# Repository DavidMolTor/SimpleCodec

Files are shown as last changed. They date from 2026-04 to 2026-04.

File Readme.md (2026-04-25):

# PICO FX

A simple stereo guitar effects platform using an RP Pico 2 development board.

## Introduction

This module is designed to be used as a development platform for guitar effects running on the RP2350 architecture.

The module contains a CS4272 codec with stereo inputs and outputs. It also includes a set of clean buffers to match the guitar and other effects in the chain.

All the power regulation is done through LDO regulators that prioritize low ripple in exchange for worse efficiency.

It is designed to work with 9V intput voltage. It also has a set of headers for it to be able to interface with a control board in the future.

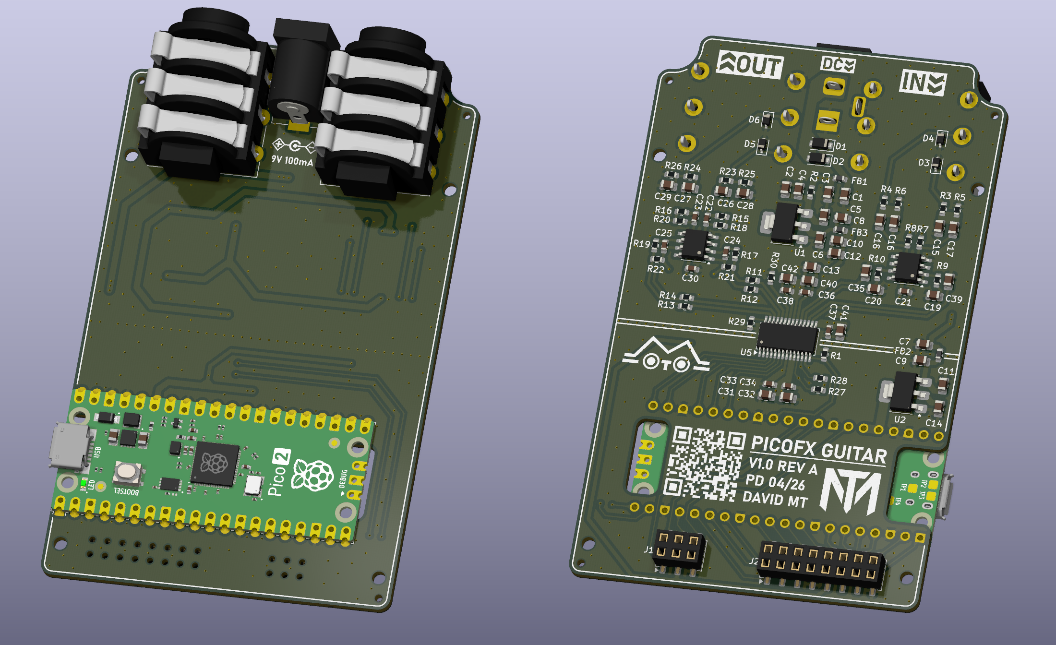
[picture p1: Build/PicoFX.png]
PICO FX


## Features

 - Clear separation between digital and analog sections.

 - Stereo input and output.

 - Clean voltage delivery.

 - Flexible interface for controls.

 - Easy future development.

 - Afforable BOM.

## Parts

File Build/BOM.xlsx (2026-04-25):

Designator | Qty | Value | Footprint | JLCPCB Part | Manufacturer Part
A1 | 1 | RP_PICO_2 | RP_PICO_2_SMD | C41407547 | Pico 2
C1,C2,C3,C4,C5,C6,C7,C8,C9,C10,C11,C12,C13,C14,C17,C18,C26,C27,C42 | 19 | 10u | 0805_2012Metric | C15850 | CL21A106KAYNNNE
C15,C16,C19,C20,C28,C29,C35,C39 | 8 | 2.2n | 0805_2012Metric | C28260 | CL21C222JBFNNNE
C21,C30,C33,C34,C36,C37,C38 | 7 | 100n | 0603_1608Metric | C14663 | CC0603KRX7R9BB104
C22,C23,C24,C25 | 4 | 330p | 0603_1608Metric | C1664 | CL10C331JB8NNNC
C31,C32,C40,C41 | 4 | 1u | 0805_2012Metric | C28323 | CL21B105KBFNNNE
D1 | 1 | SMF10CA | SOD-123F | C19077505 | SMF10CA
D2 | 1 | DSK24 | SOD-123F | C22466352 | DSK24
D3,D4,D5,D6 | 4 | H15VSD3B | SOD-323 | C20615814 | H15VSD3B
FB1,FB2,FB3 | 3 | 850 | 0603_1608Metric | C13415 | SDCL1608C68NJTDF
J1 | 1 | RPI_ADC | HEADER_THROUGH_2x03_P2.54mm | C42163131 | HC-PM254-5.0H-2x3PS-02A
J2 | 1 | RP_GPIO | HEADER_THROUGH_2x08_P2.54mm | C42163136 | HC-PM254-5.0H-2x8PS
R1,R25,R26,R27,R28,R29,R30 | 7 | 47K | 0603_1608Metric | C25819 | 0603WAF4702T5E
R2,R3,R4,R23,R24 | 5 | 100 | 0603_1608Metric | C22775 | 0603WAF1000T5E
R5,R6,R7,R8 | 4 | 1M | 0603_1608Metric | C22935 | 0603WAF1004T5E
R9,R10 | 2 | 1K | 0603_1608Metric | C21190 | 0603WAF1001T5E
R11,R12,R13,R14 | 4 | 15K | 0603_1608Metric | C22809 | 0603WAF1502T5E
R15,R16,R21,R22 | 4 | 11K | 0603_1608Metric | C25950 | 0603WAF1102T5E
R17,R18,R19,R20 | 4 | 820 | 0603_1608Metric | C23253 | 0603WAF8200T5E
U1 | 1 | AMS1117-5.0 | SOT-223-3_TabPin2 | C6187 | AMS1117-5.0
U2 | 1 | AMS1117-3.3 | SOT-223-3_TabPin2 | C6186 | AMS1117-3.3
U3,U4 | 2 | MCP6002-xSN | SOIC-8_3.9x4.9mm_P1.27mm | C7377 | MCP6002T-I/SN
U5 | 1 | CS4272 | TSSOP-28_4.4x9.7mm_P0.65mm | C2151111 | CS4272-CZZR
X1-GUITAR | 2 | JACK_GUITAR | NMJ6HCD2 | C368502 | NMJ6HCD2
X1-DC | 1 | JACK_DC | BarrelJack_Horizontal | C319099 | DC-005-2.5A-2.0

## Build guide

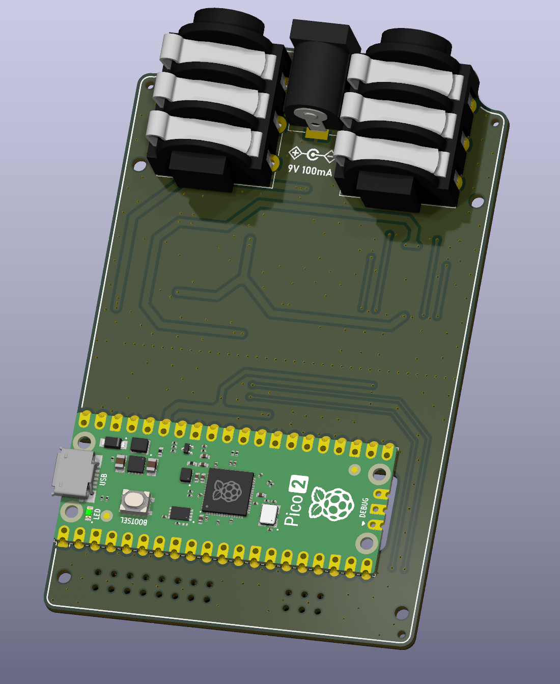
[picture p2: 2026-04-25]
Build/Front.png

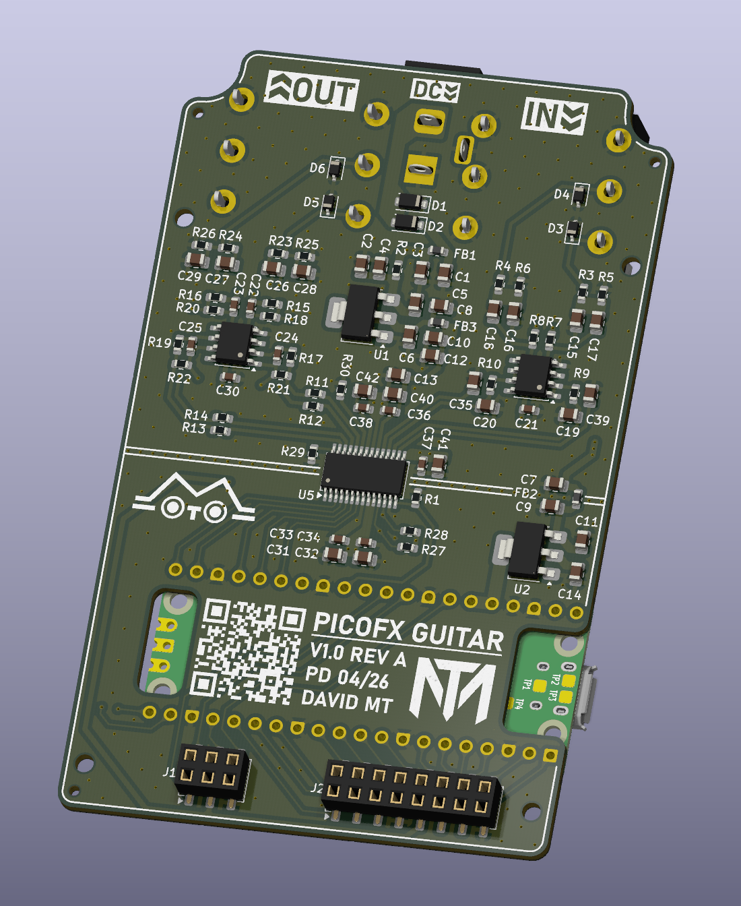
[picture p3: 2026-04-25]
Build/Back.png

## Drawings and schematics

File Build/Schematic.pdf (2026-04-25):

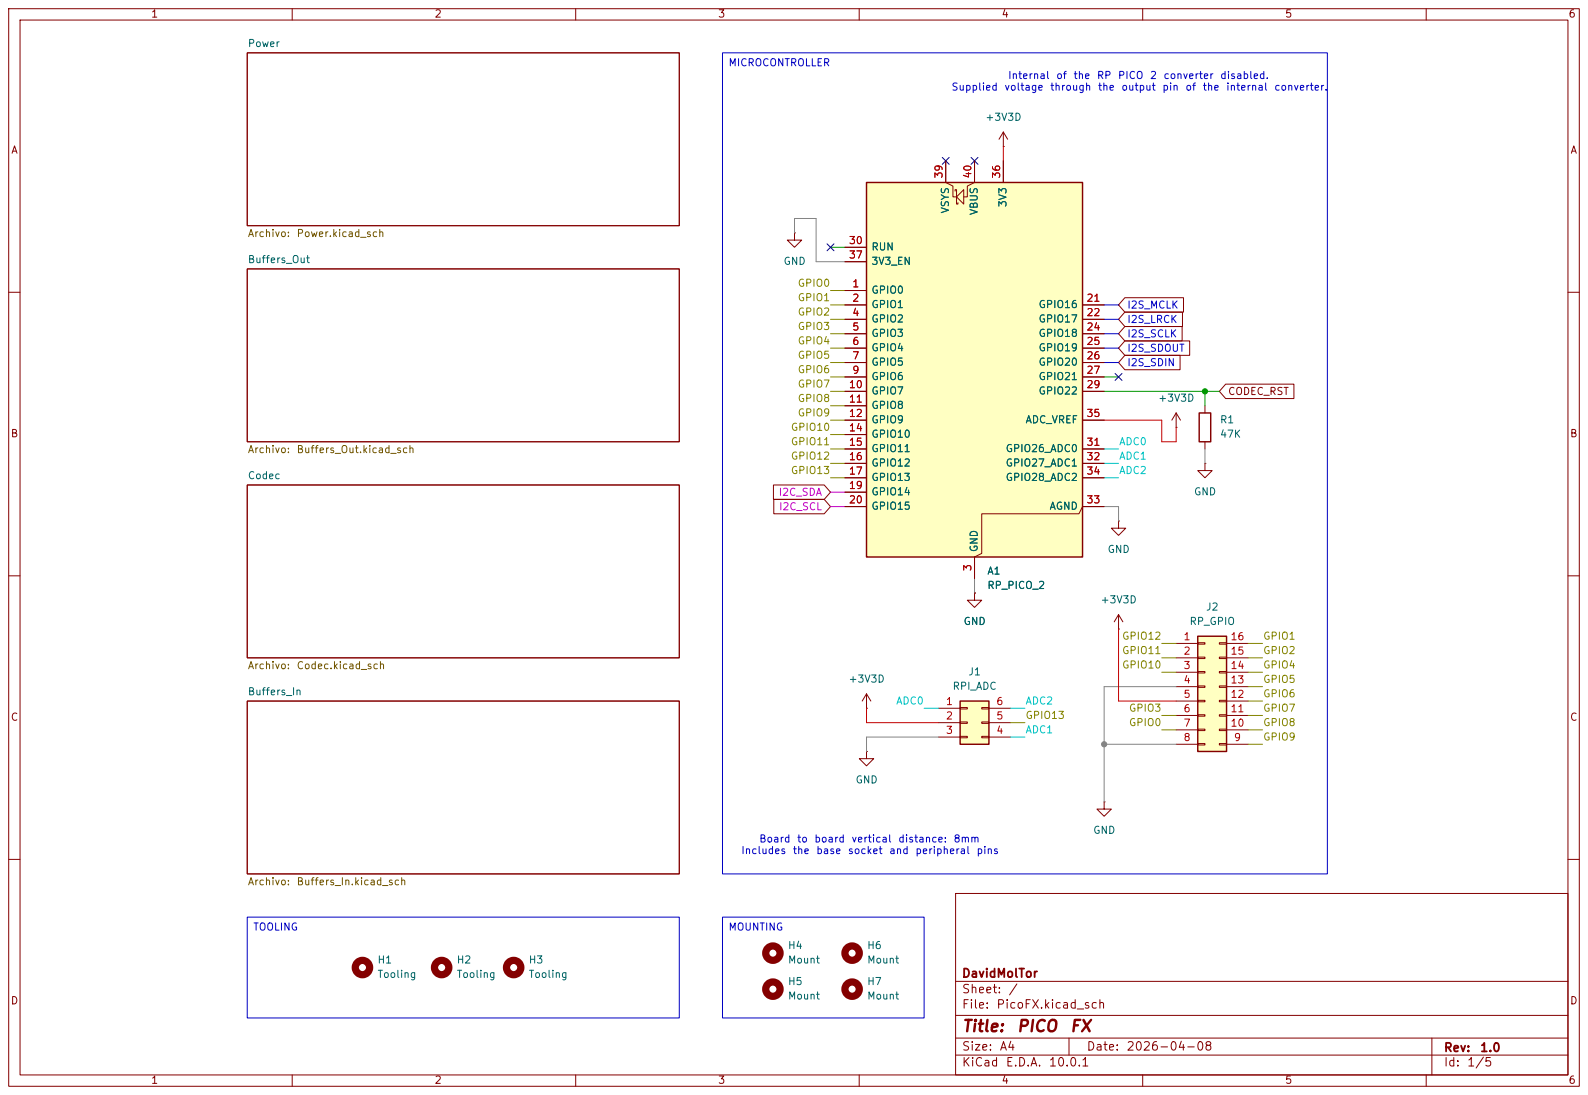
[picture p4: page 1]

Internal of the RP PICO 2 converter disabled. Supplied voltage through the output pin of the internal converter.

Includes the base socket and peripheral pins GND

Board to board vertical distance: 8mm

Size: A4 | Rev: 1.0
KiCad E.D.A. 10.0.1 | Id: 1/5

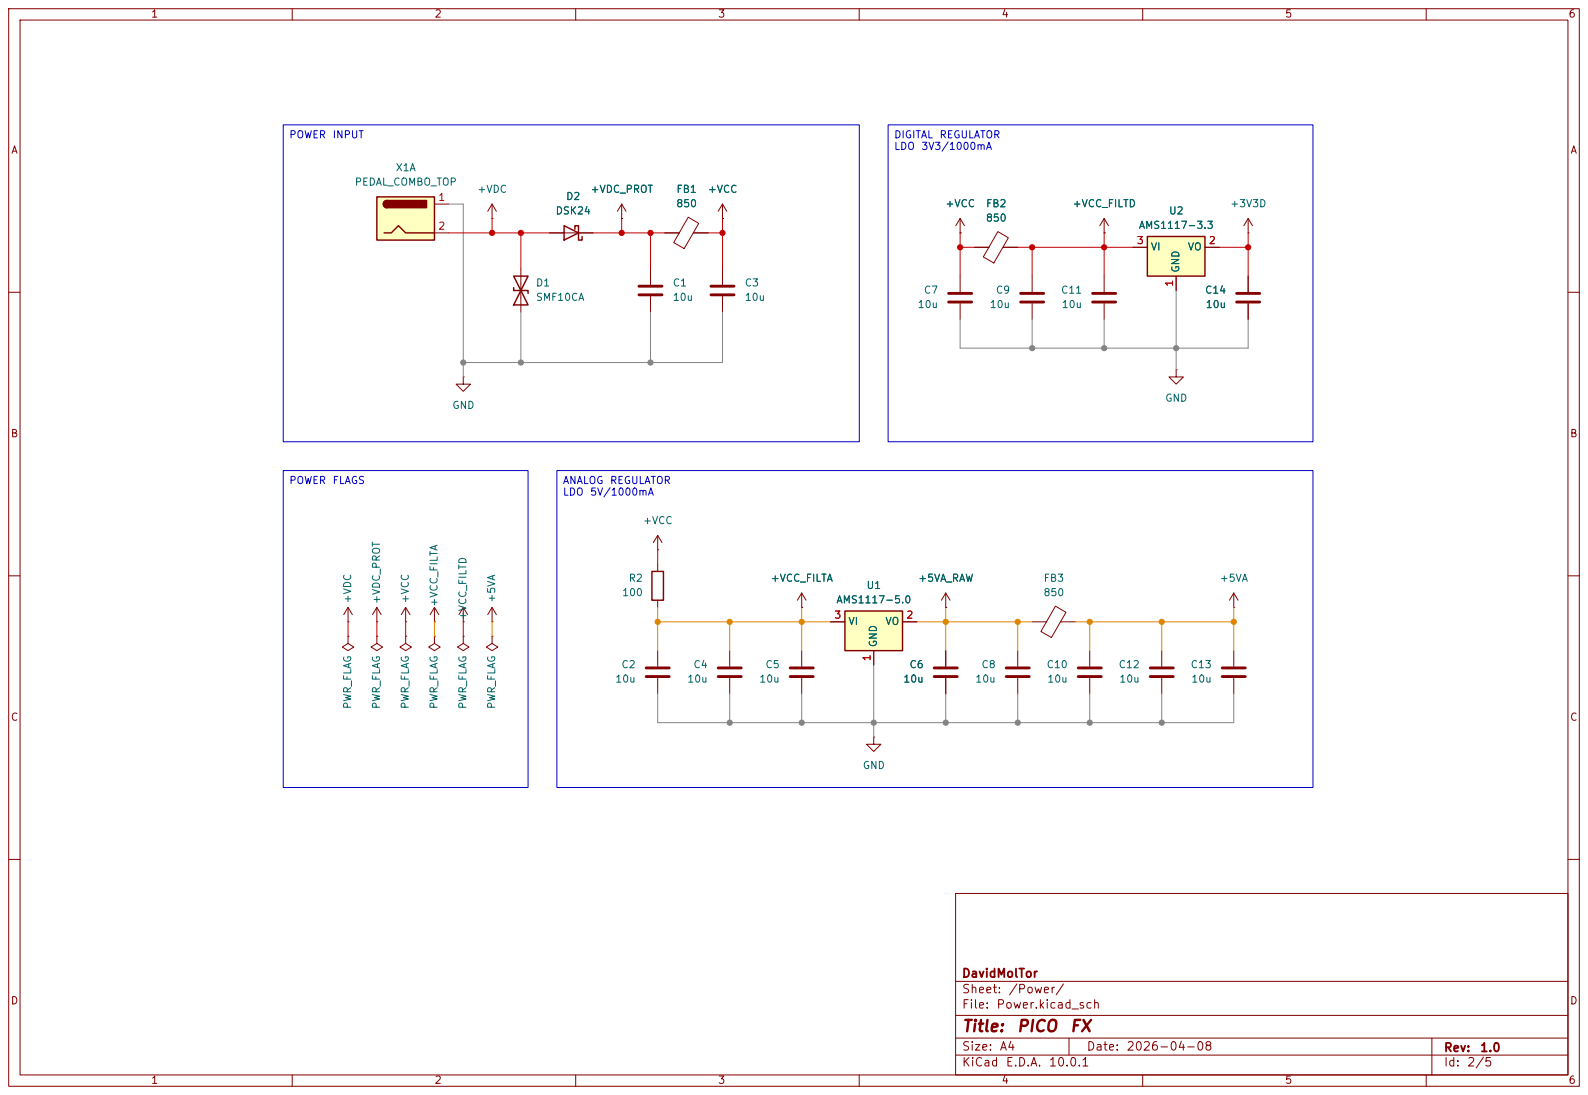
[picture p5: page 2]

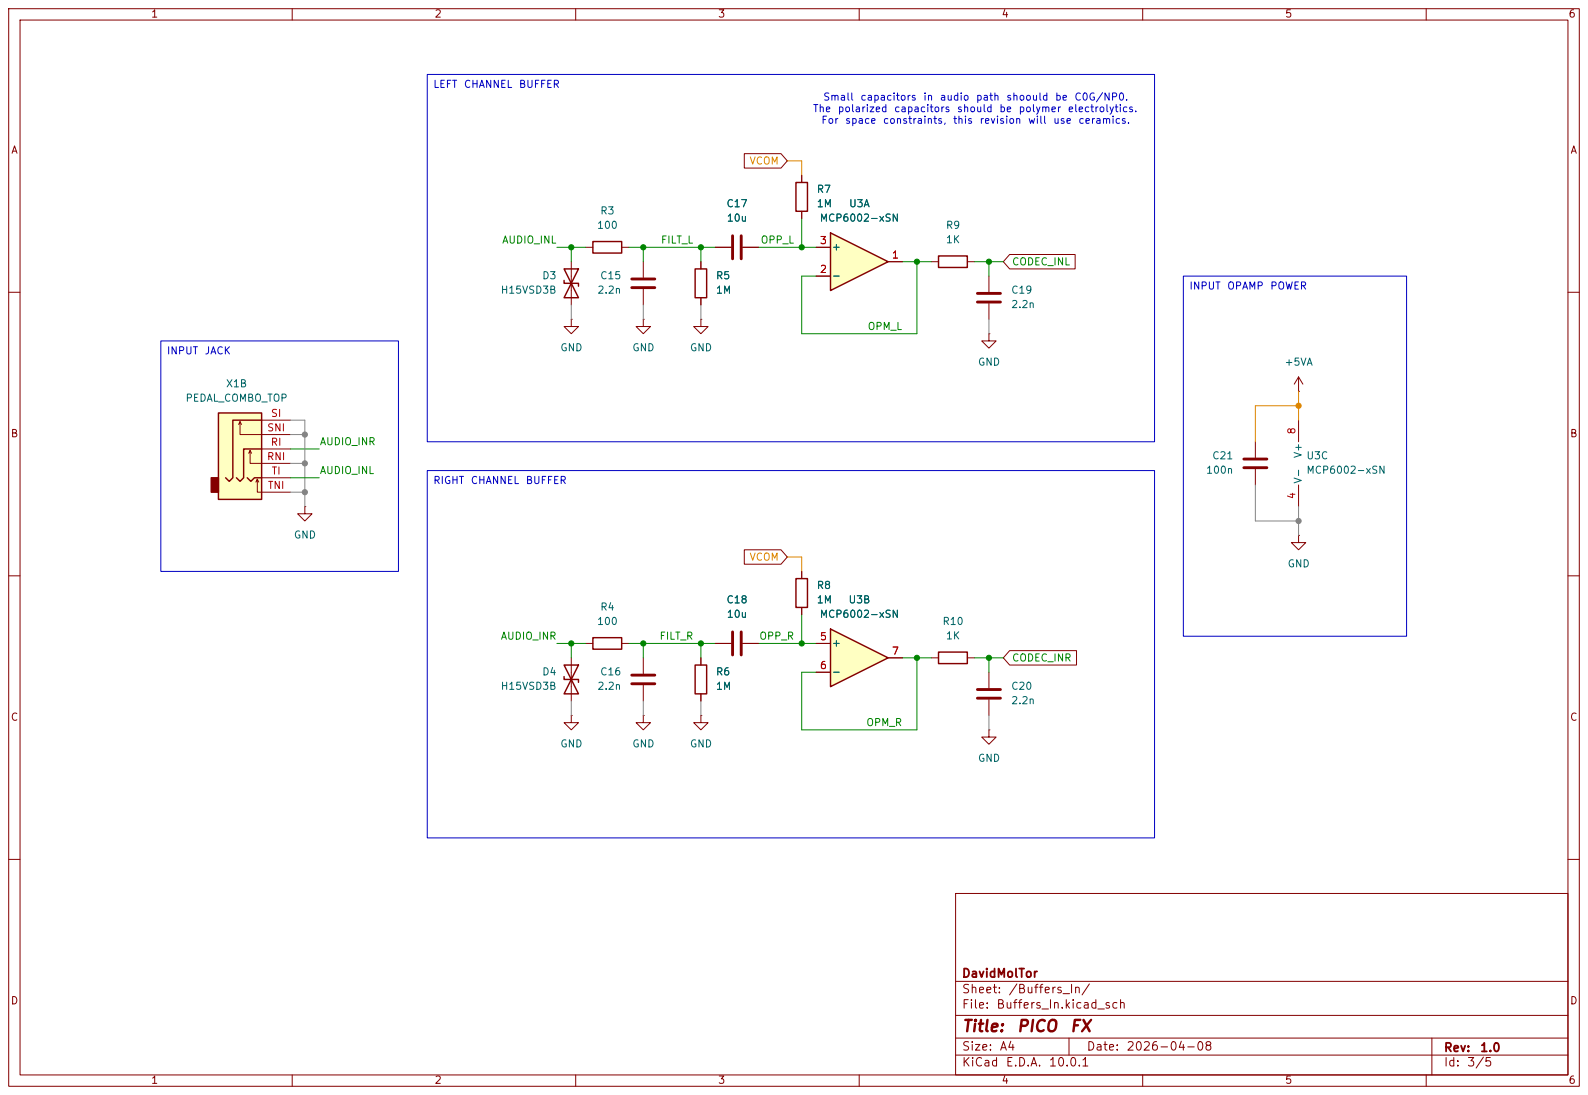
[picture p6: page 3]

Small capacitors in audio path shoould be C0G/NP0. The polarized capacitors should be polymer electrolytics. For space constraints, this revision will use ceramics. U3A MCP6002-xSN

RI RNI SI SNI TI TNI X1B

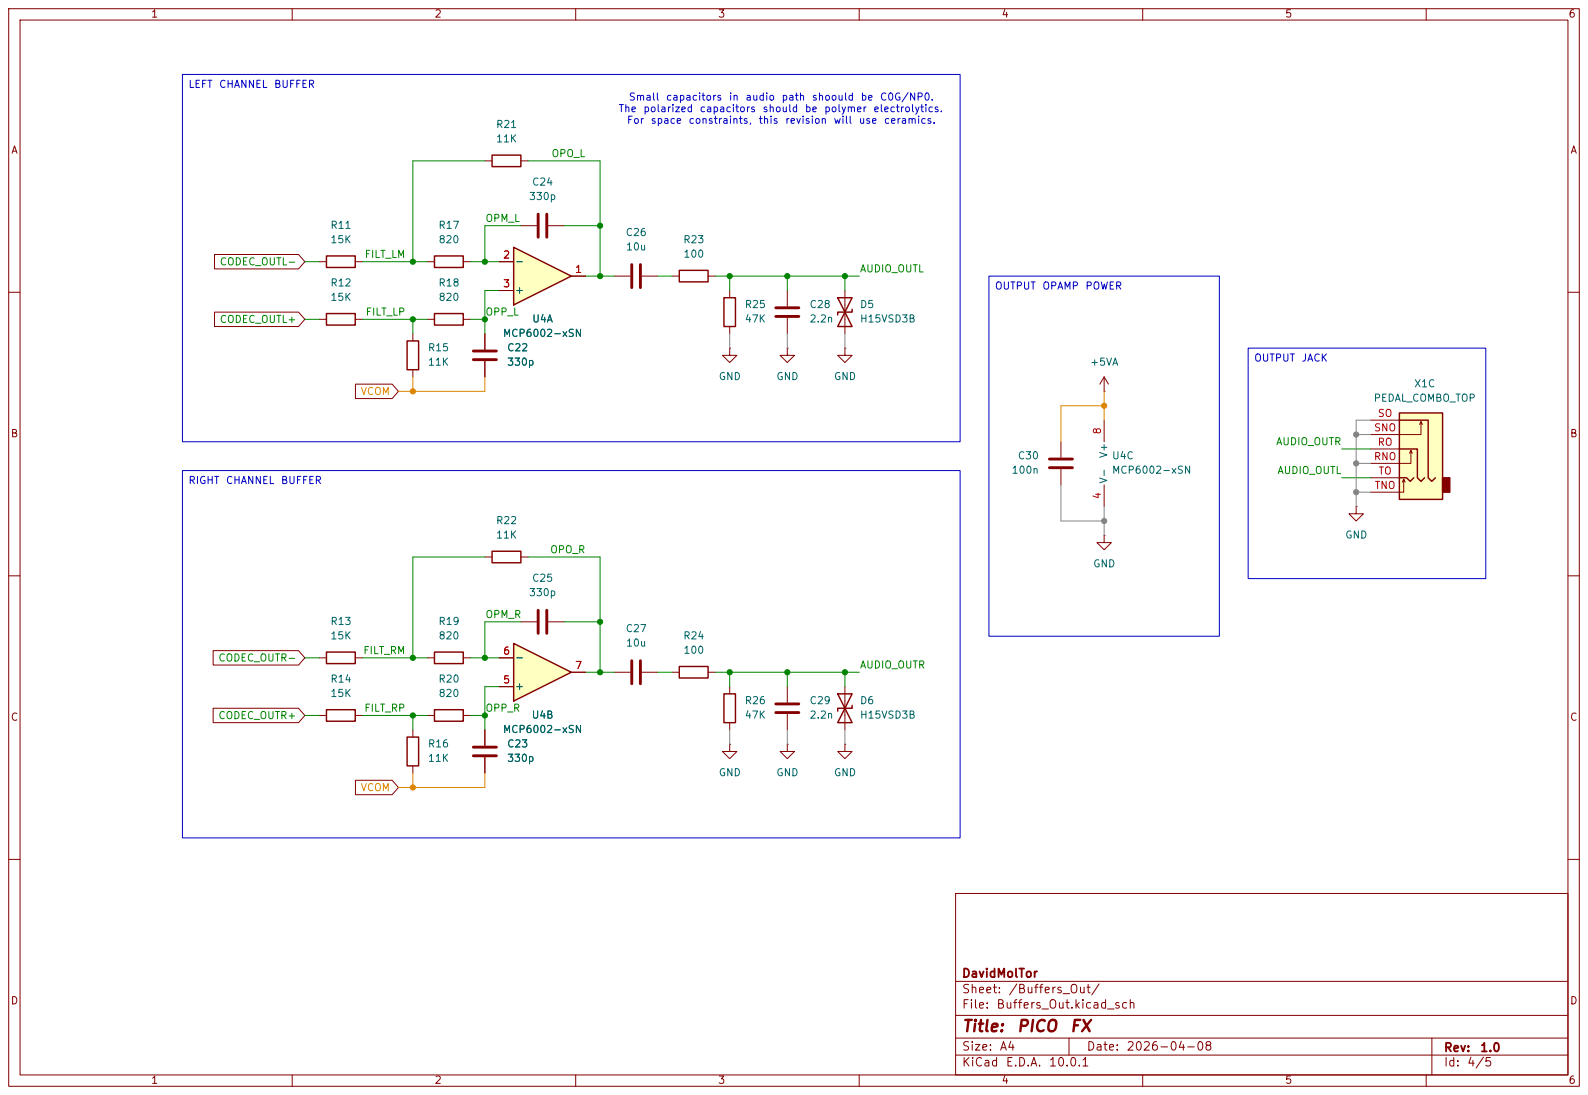
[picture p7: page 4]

Small capacitors in audio path shoould be C0G/NP0. The polarized capacitors should be polymer electrolytics. For space constraints, this revision will use ceramics. U4A MCP6002-xSN

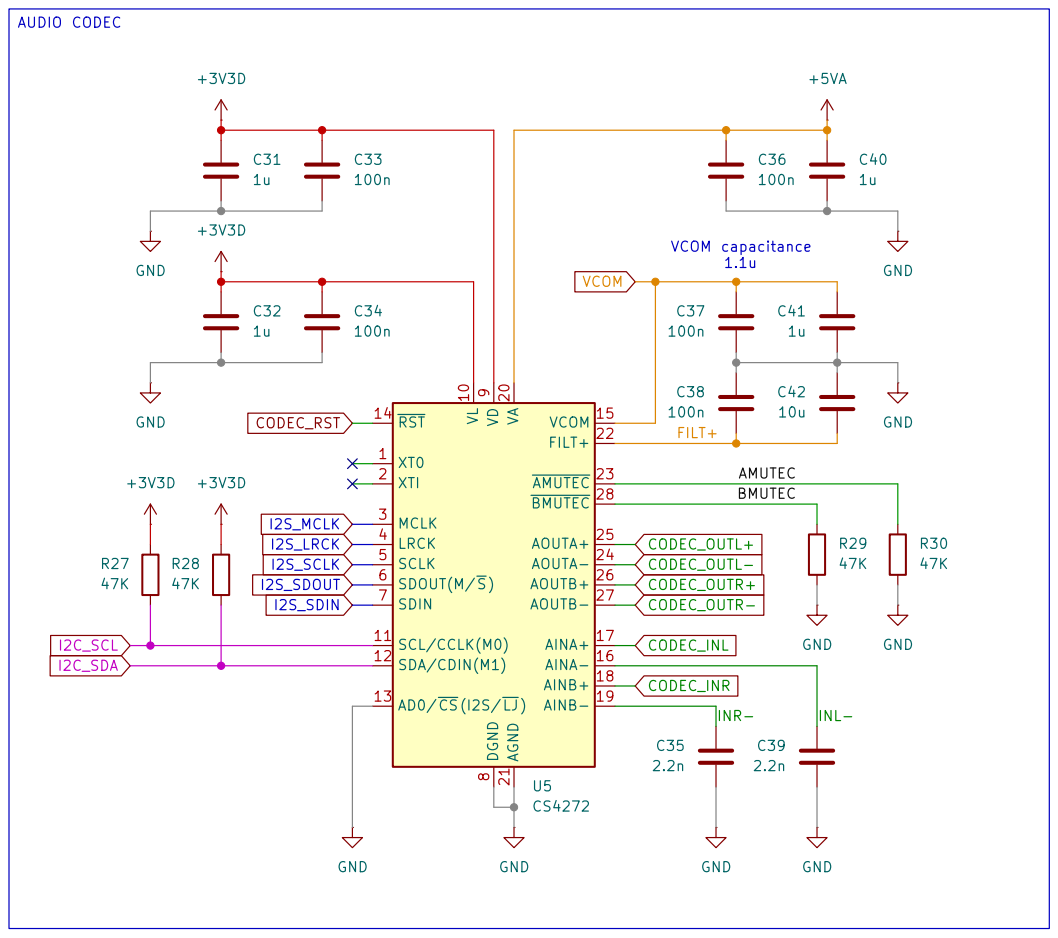
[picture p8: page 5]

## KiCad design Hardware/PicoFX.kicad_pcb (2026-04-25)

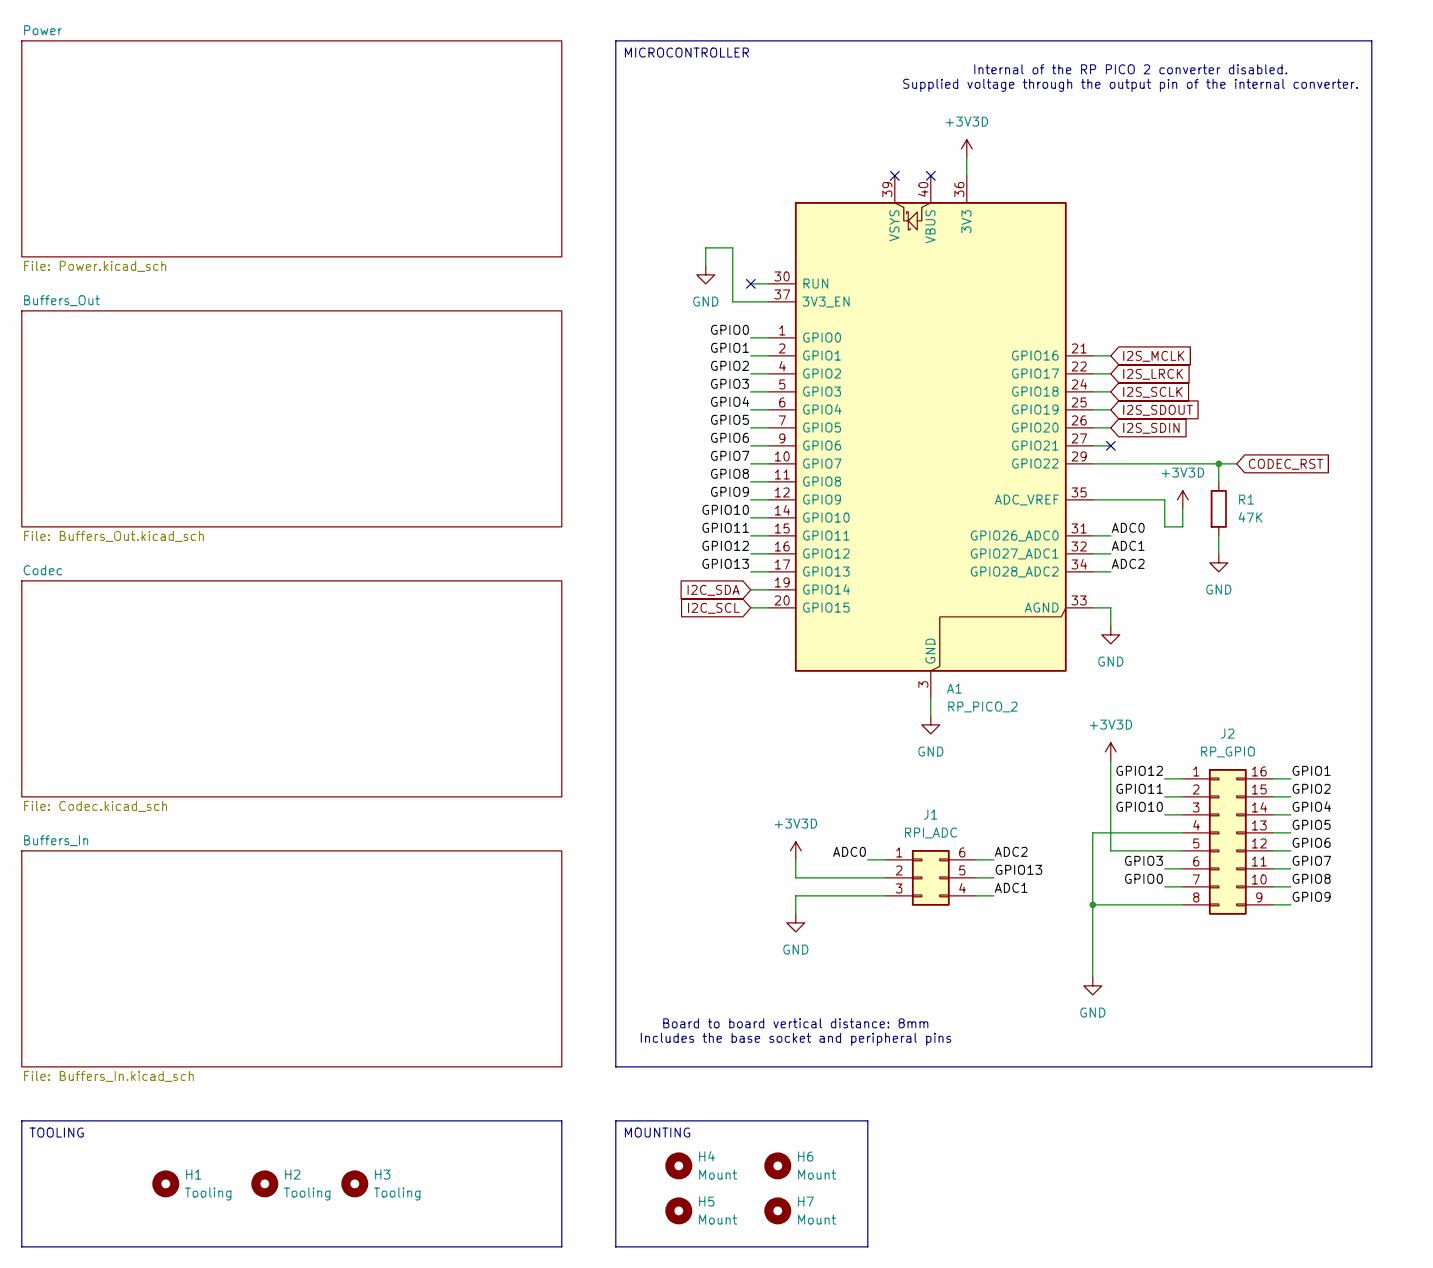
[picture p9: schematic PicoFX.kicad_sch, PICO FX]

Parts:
A1: RP_PICO_2; RP_PICO_2_SMD
H1, H2, H3: Tooling; ToolingHole_1.152mm
H4, H5, H6, H7: Mount; MountingHole_2.2mm_M2
J1: RPI_ADC; HEADER_THROUGH_2x03_P2.54mm
J2: RP_GPIO; HEADER_THROUGH_2x08_P2.54mm
R1: 47K; R_0603_1608Metric

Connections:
+3V3D: A1.35 (ADC_VREF), A1.36 (3V3), J1.2, J2.5; also elsewhere on the board
/ADC0: A1.31 (GPIO26_ADC0), J1.1
/ADC1: A1.32 (GPIO27_ADC1), J1.4
/ADC2: A1.34 (GPIO28_ADC2), J1.6
/GPIO0: A1.1 (GPIO0), J2.7
/GPIO1: A1.2 (GPIO1), J2.16
/GPIO2: A1.4 (GPIO2), J2.15
/GPIO3: A1.5 (GPIO3), J2.6
/GPIO4: A1.6 (GPIO4), J2.14
/GPIO5: A1.7 (GPIO5), J2.13
/GPIO6: A1.9 (GPIO6), J2.12
/GPIO7: A1.10 (GPIO7), J2.11
/GPIO8: A1.11 (GPIO8), J2.10
/GPIO9: A1.12 (GPIO9), J2.9
/GPIO10: A1.14 (GPIO10), J2.3
/GPIO11: A1.15 (GPIO11), J2.2
/GPIO12: A1.16 (GPIO12), J2.1
/GPIO13: A1.17 (GPIO13), J1.5
CODEC_RST: A1.29 (GPIO22), R1.1; also elsewhere on the board
GND: A1.3 (GND), A1.8 (GND), A1.13 (GND), A1.18 (GND), A1.23 (GND), A1.28 (GND), A1.33 (AGND), A1.37 (3V3_EN), A1.38 (GND), J1.3, J2.4, J2.8, R1.2; also elsewhere on the board
I2C_SCL: A1.20 (GPIO15); also elsewhere on the board
I2C_SDA: A1.19 (GPIO14); also elsewhere on the board
I2S_LRCK: A1.22 (GPIO17); also elsewhere on the board
I2S_MCLK: A1.21 (GPIO16); also elsewhere on the board
I2S_SCLK: A1.24 (GPIO18); also elsewhere on the board
I2S_SDIN: A1.26 (GPIO20); also elsewhere on the board
I2S_SDOUT: A1.25 (GPIO19); also elsewhere on the board

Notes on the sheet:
Board to board vertical distance: 8mm Includes the base socket and peripheral pins
Internal of the RP PICO 2 converter disabled. Supplied voltage through the output pin of the internal converter.
MICROCONTROLLER
TOOLING
MOUNTING

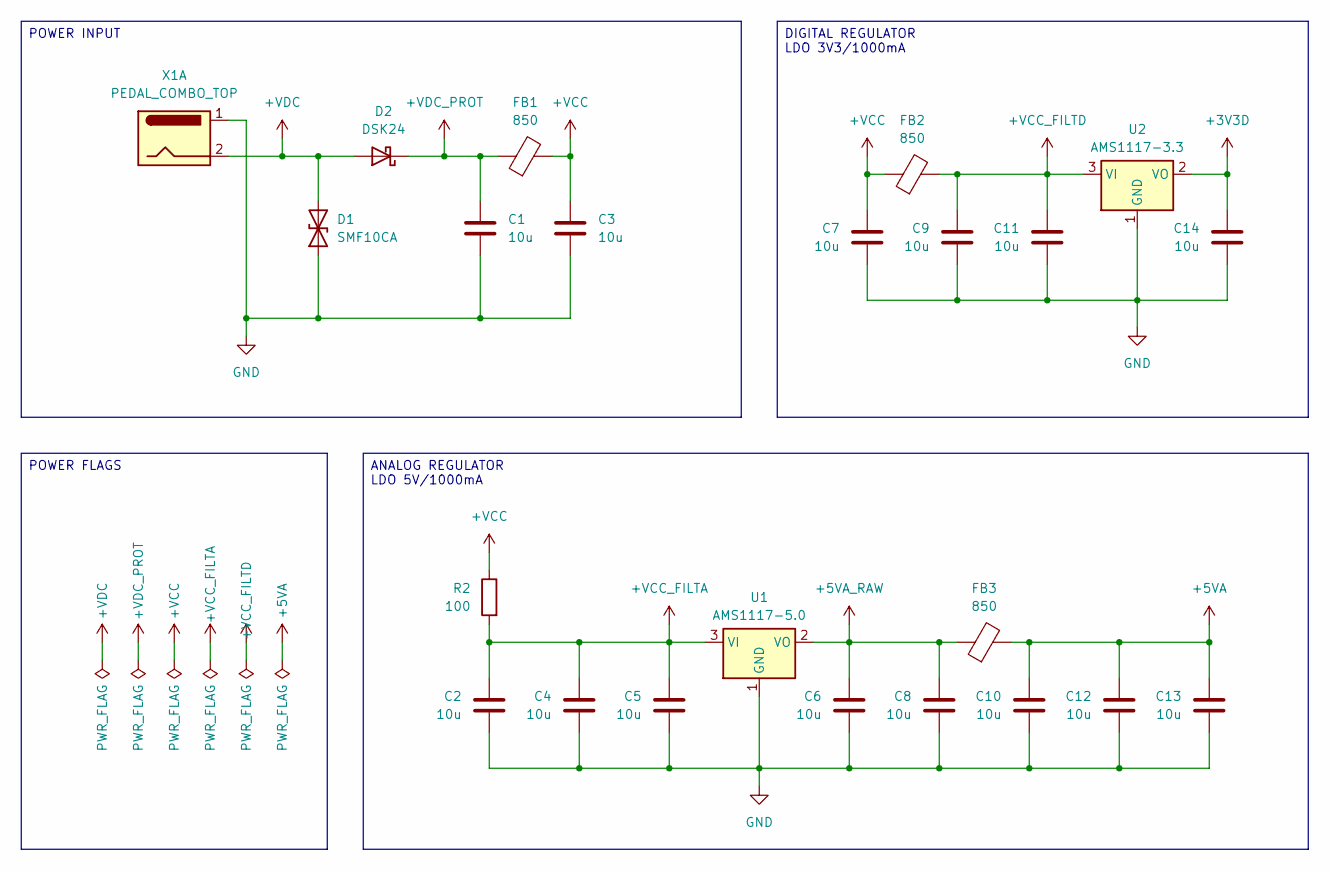
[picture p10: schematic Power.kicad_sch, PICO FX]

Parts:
C1, C2, C3, C4, C5, C6, C7, C8, C9, C10, C11, C12, C13, C14: 10u; C_0805_2012Metric
D1: SMF10CA; D_SOD-123F
D2: DSK24; D_SOD-123F
FB1, FB2, FB3: 850; L_0603_1608Metric
R2: 100; R_0603_1608Metric
U1: AMS1117-5.0; SOT-223-3_TabPin2
U2: AMS1117-3.3; SOT-223-3_TabPin2
X1: PEDAL_COMBO_TOP

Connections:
+3V3D: C14.1, U2.2 (VO); also elsewhere on the board
+5VA: C10.1, C12.1, C13.1, FB3.2; also elsewhere on the board
+5VA_RAW: C6.1, C8.1, FB3.1, U1.2 (VO)
+VCC: C3.1, C7.1, FB1.2, FB2.1, R2.1
+VCC_FILTA: C2.1, C4.1, C5.1, R2.2, U1.3 (VI)
+VCC_FILTD: C9.1, C11.1, FB2.2, U2.3 (VI)
+VDC: D1.2 (A2), D2.2 (A), X1.2
+VDC_PROT: C1.1, D2.1 (K), FB1.1
GND: C1.2, C2.2, C3.2, C4.2, C5.2, C6.2, C7.2, C8.2, C9.2, C10.2, C11.2, C12.2, C13.2, C14.2, D1.1 (A1), U1.1 (GND), U2.1 (GND), X1.1; also elsewhere on the board

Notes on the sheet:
DIGITAL REGULATOR LDO 3V3/1000mA
POWER INPUT
ANALOG REGULATOR LDO 5V/1000mA
POWER FLAGS

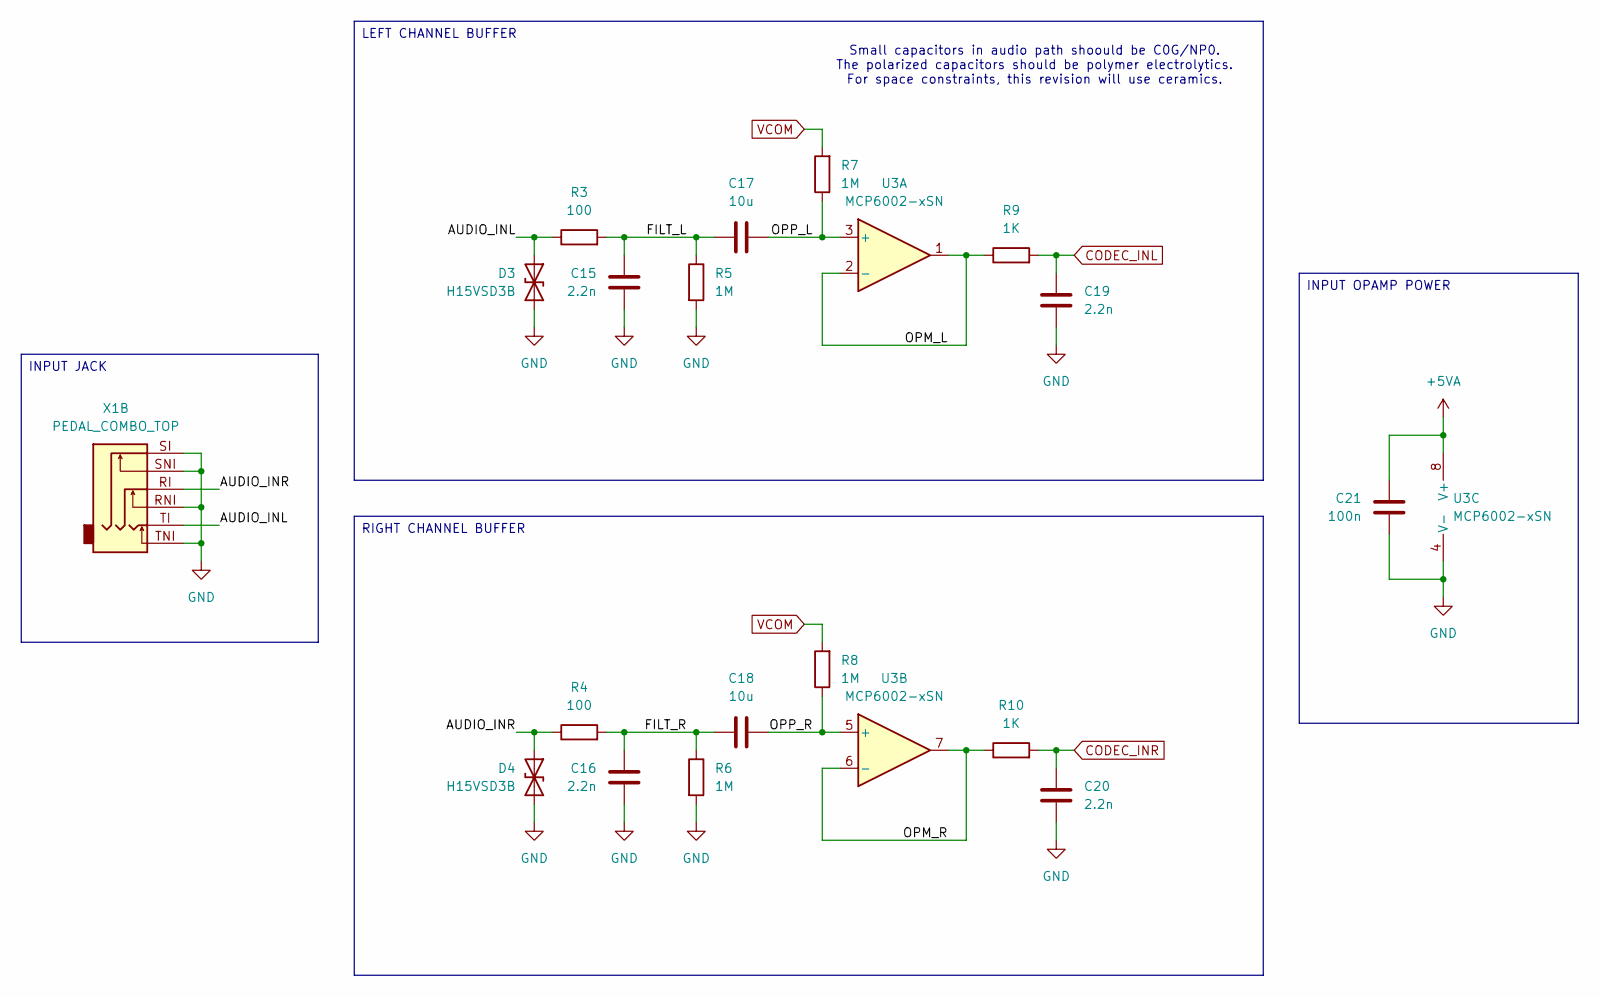
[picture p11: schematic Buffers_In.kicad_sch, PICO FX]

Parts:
C15, C16, C19, C20: 2.2n; C_0805_2012Metric
C17, C18: 10u; C_0805_2012Metric
C21: 100n; C_0603_1608Metric
D3, D4: H15VSD3B; D_SOD-323
R3, R4: 100; R_0603_1608Metric
R5, R6, R7, R8: 1M; R_0603_1608Metric
R9, R10: 1K; R_0603_1608Metric
U3: MCP6002-xSN; SOIC-8_3.9x4.9mm_P1.27mm
X1: PEDAL_COMBO_TOP

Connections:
+5VA: C21.1, U3.8 (V+); also elsewhere on the board
/Buffers_In/AUDIO_INL: D3.1 (A1), R3.1, X1.TI
/Buffers_In/AUDIO_INR: D4.1 (A1), R4.1, X1.RI
/Buffers_In/FILT_L: C15.2, C17.1, R3.2, R5.1
/Buffers_In/FILT_R: C16.2, C18.1, R4.2, R6.1
/Buffers_In/OPM_L: R9.1, U3.1, U3.2 (-)
/Buffers_In/OPM_R: R10.1, U3.6 (-), U3.7
/Buffers_In/OPP_L: C17.2, R7.1, U3.3 (+)
/Buffers_In/OPP_R: C18.2, R8.1, U3.5 (+)
CODEC_INL: C19.1, R9.2; also elsewhere on the board
CODEC_INR: C20.1, R10.2; also elsewhere on the board
GND: C15.1, C16.1, C19.2, C20.2, C21.2, D3.2 (A2), D4.2 (A2), R5.2, R6.2, U3.4 (V-), X1.RNI, X1.SI, X1.SNI, X1.TNI; also elsewhere on the board
VCOM: R7.2, R8.2; also elsewhere on the board

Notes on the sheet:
Small capacitors in audio path shoould be C0G/NP0. The polarized capacitors should be polymer electrolytics. For space constraints, this revision will use ceramics.
LEFT CHANNEL BUFFER
INPUT OPAMP POWER
INPUT JACK
RIGHT CHANNEL BUFFER

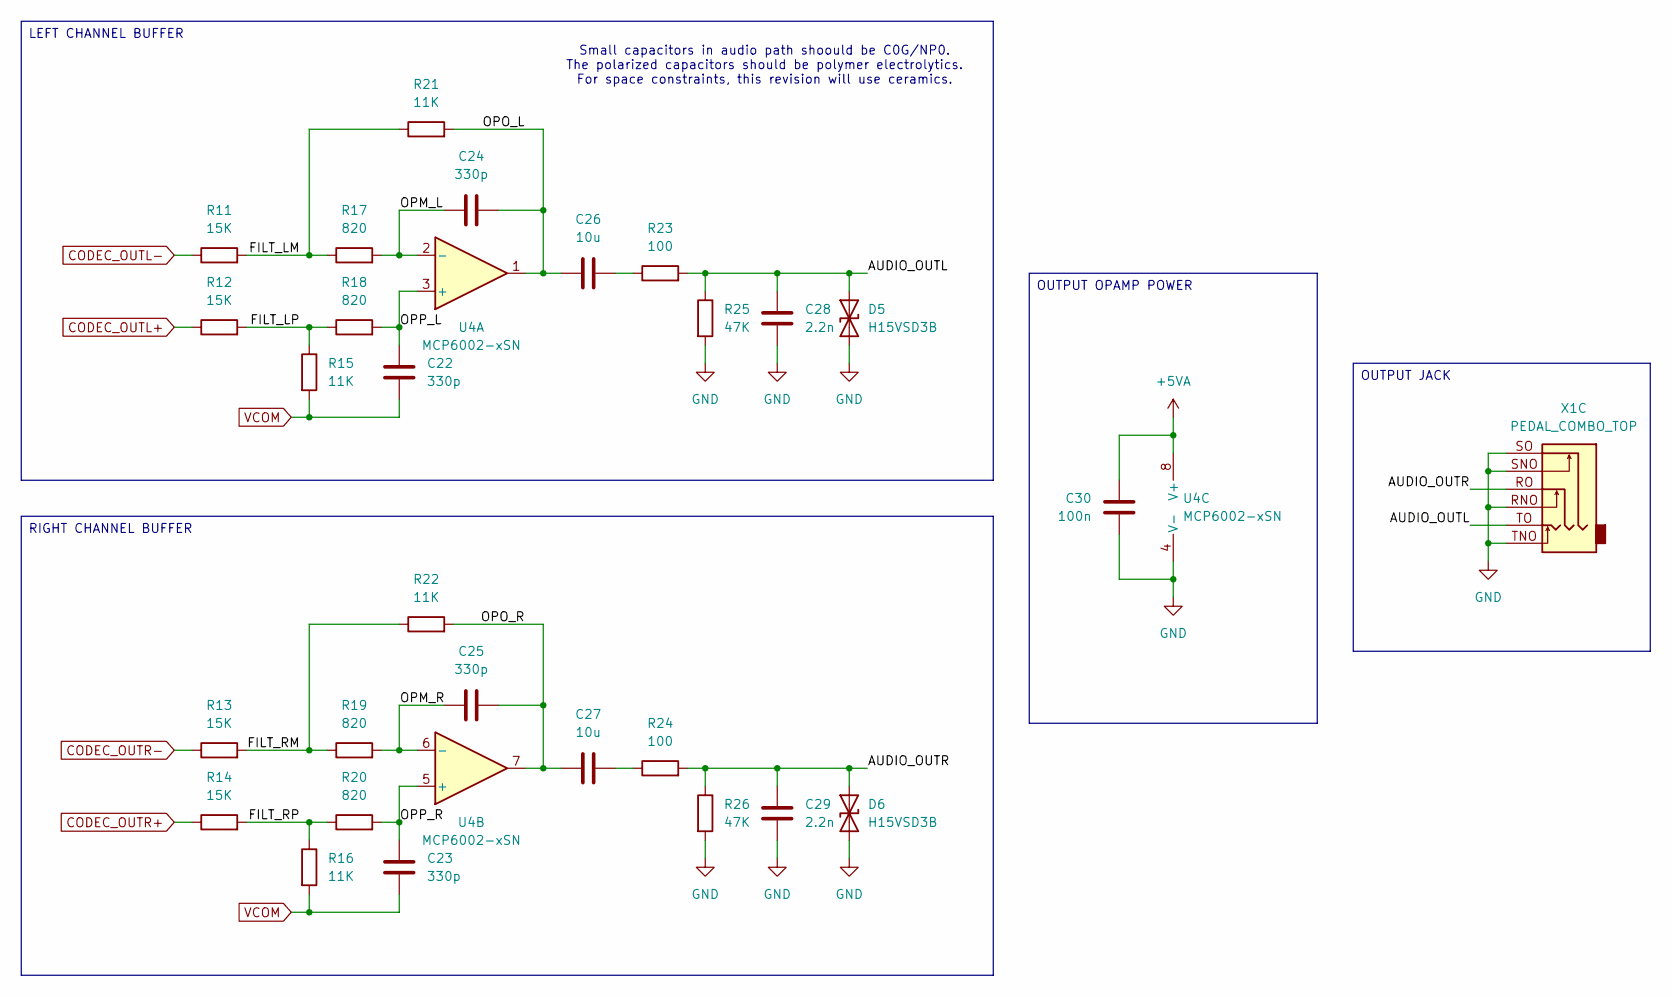
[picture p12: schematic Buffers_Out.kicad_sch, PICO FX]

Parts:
C22, C23, C24, C25: 330p; C_0603_1608Metric
C26, C27: 10u; C_0805_2012Metric
C28, C29: 2.2n; C_0805_2012Metric
C30: 100n; C_0603_1608Metric
D5, D6: H15VSD3B; D_SOD-323
R11, R12, R13, R14: 15K; R_0603_1608Metric
R15, R16, R21, R22: 11K; R_0603_1608Metric
R17, R18, R19, R20: 820; R_0603_1608Metric
R23, R24: 100; R_0603_1608Metric
R25, R26: 47K; R_0603_1608Metric
U4: MCP6002-xSN; SOIC-8_3.9x4.9mm_P1.27mm
X1: PEDAL_COMBO_TOP

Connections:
+5VA: C30.1, U4.8 (V+); also elsewhere on the board
/Buffers_Out/AUDIO_OUTL: C28.1, D5.1 (A1), R23.2, R25.1, X1.TO
/Buffers_Out/AUDIO_OUTR: C29.1, D6.1 (A1), R24.2, R26.1, X1.RO
/Buffers_Out/FILT_LM: R11.2, R17.1, R21.1
/Buffers_Out/FILT_LP: R12.2, R15.1, R18.1
/Buffers_Out/FILT_RM: R13.2, R19.1, R22.1
/Buffers_Out/FILT_RP: R14.2, R16.1, R20.1
/Buffers_Out/OPM_L: C24.1, R17.2, U4.2 (-)
/Buffers_Out/OPM_R: C25.1, R19.2, U4.6 (-)
/Buffers_Out/OPO_L: C24.2, C26.1, R21.2, U4.1
/Buffers_Out/OPO_R: C25.2, C27.1, R22.2, U4.7
/Buffers_Out/OPP_L: C22.1, R18.2, U4.3 (+)
/Buffers_Out/OPP_R: C23.1, R20.2, U4.5 (+)
CODEC_OUTL+: R12.1; also elsewhere on the board
CODEC_OUTL-: R11.1; also elsewhere on the board
CODEC_OUTR+: R14.1; also elsewhere on the board
CODEC_OUTR-: R13.1; also elsewhere on the board
GND: C28.2, C29.2, C30.2, D5.2 (A2), D6.2 (A2), R25.2, R26.2, U4.4 (V-), X1.RNO, X1.SNO, X1.SO, X1.TNO; also elsewhere on the board
unnamed: C26.2, R23.1
unnamed: C27.2, R24.1
VCOM: C22.2, C23.2, R15.2, R16.2; also elsewhere on the board

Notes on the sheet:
Small capacitors in audio path shoould be C0G/NP0. The polarized capacitors should be polymer electrolytics. For space constraints, this revision will use ceramics.
OUTPUT JACK
LEFT CHANNEL BUFFER
RIGHT CHANNEL BUFFER
OUTPUT OPAMP POWER

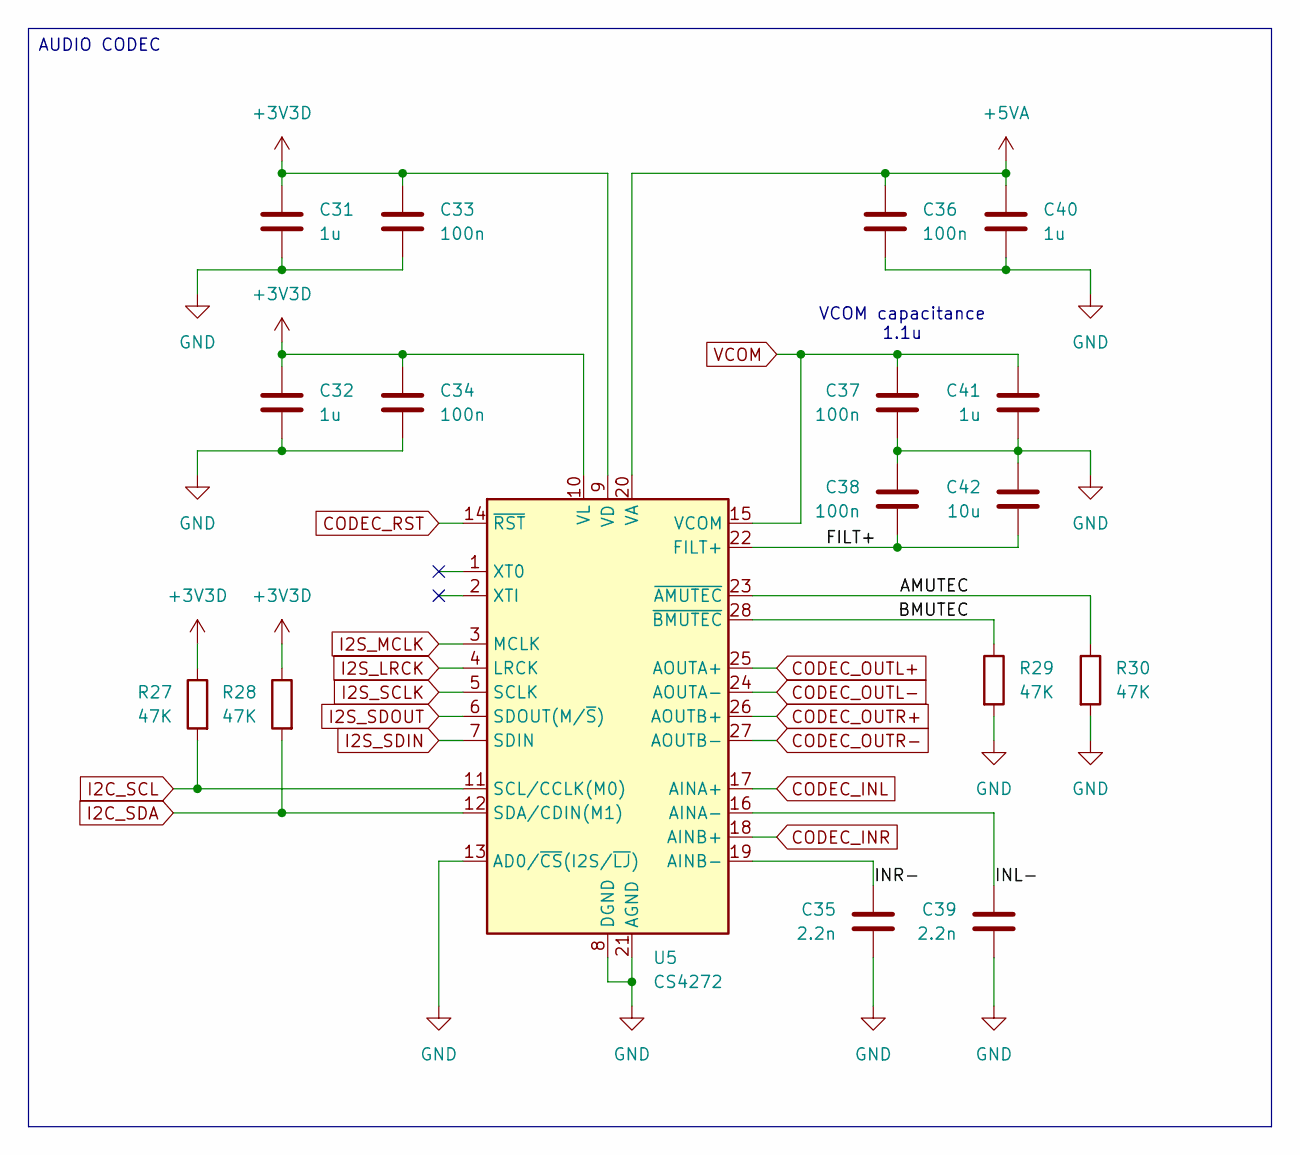
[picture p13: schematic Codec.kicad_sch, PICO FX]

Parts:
C31, C32, C40, C41: 1u; C_0805_2012Metric
C33, C34, C36, C37, C38: 100n; C_0603_1608Metric
C35, C39: 2.2n; C_0805_2012Metric
C42: 10u; C_0805_2012Metric
R27, R28, R29, R30: 47K; R_0603_1608Metric
U5: CS4272; TSSOP-28_4.4x9.7mm_P0.65mm

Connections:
+3V3D: C31.2, C32.2, C33.1, C34.1, R27.1, R28.1, U5.9 (VD), U5.10 (VL); also elsewhere on the board
+5VA: C36.2, C40.1, U5.20 (VA); also elsewhere on the board
/Codec/AMUTEC: R30.1, U5.23 (~AMUTEC)
/Codec/BMUTEC: R29.1, U5.28 (~BMUTEC)
/Codec/FILT+: C38.1, C42.2, U5.22 (FILT+)
/Codec/INL-: C39.1, U5.16 (AINA-)
/Codec/INR-: C35.1, U5.19 (AINB-)
CODEC_INL: U5.17 (AINA+); also elsewhere on the board
CODEC_INR: U5.18 (AINB+); also elsewhere on the board
CODEC_OUTL+: U5.25 (AOUTA+); also elsewhere on the board
CODEC_OUTL-: U5.24 (AOUTA-); also elsewhere on the board
CODEC_OUTR+: U5.26 (AOUTB+); also elsewhere on the board
CODEC_OUTR-: U5.27 (AOUTB-); also elsewhere on the board
CODEC_RST: U5.14 (~RST); also elsewhere on the board
GND: C31.1, C32.1, C33.2, C34.2, C35.2, C36.1, C37.2, C38.2, C39.2, C40.2, C41.2, C42.1, R29.2, R30.2, U5.8 (DGND), U5.13 (AD0/~CS(I2S/~LJ)), U5.21 (AGND); also elsewhere on the board
I2C_SCL: R27.2, U5.11 (SCL/CCLK(M0)); also elsewhere on the board
I2C_SDA: R28.2, U5.12 (SDA/CDIN(M1)); also elsewhere on the board
I2S_LRCK: U5.4 (LRCK); also elsewhere on the board
I2S_MCLK: U5.3 (MCLK); also elsewhere on the board
I2S_SCLK: U5.5 (SCLK); also elsewhere on the board
I2S_SDIN: U5.7 (SDIN); also elsewhere on the board
I2S_SDOUT: U5.6 (SDOUT(M/~S)); also elsewhere on the board
VCOM: C37.1, C41.1, U5.15 (VCOM); also elsewhere on the board

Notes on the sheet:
VCOM capacitance 1.1u
AUDIO CODEC

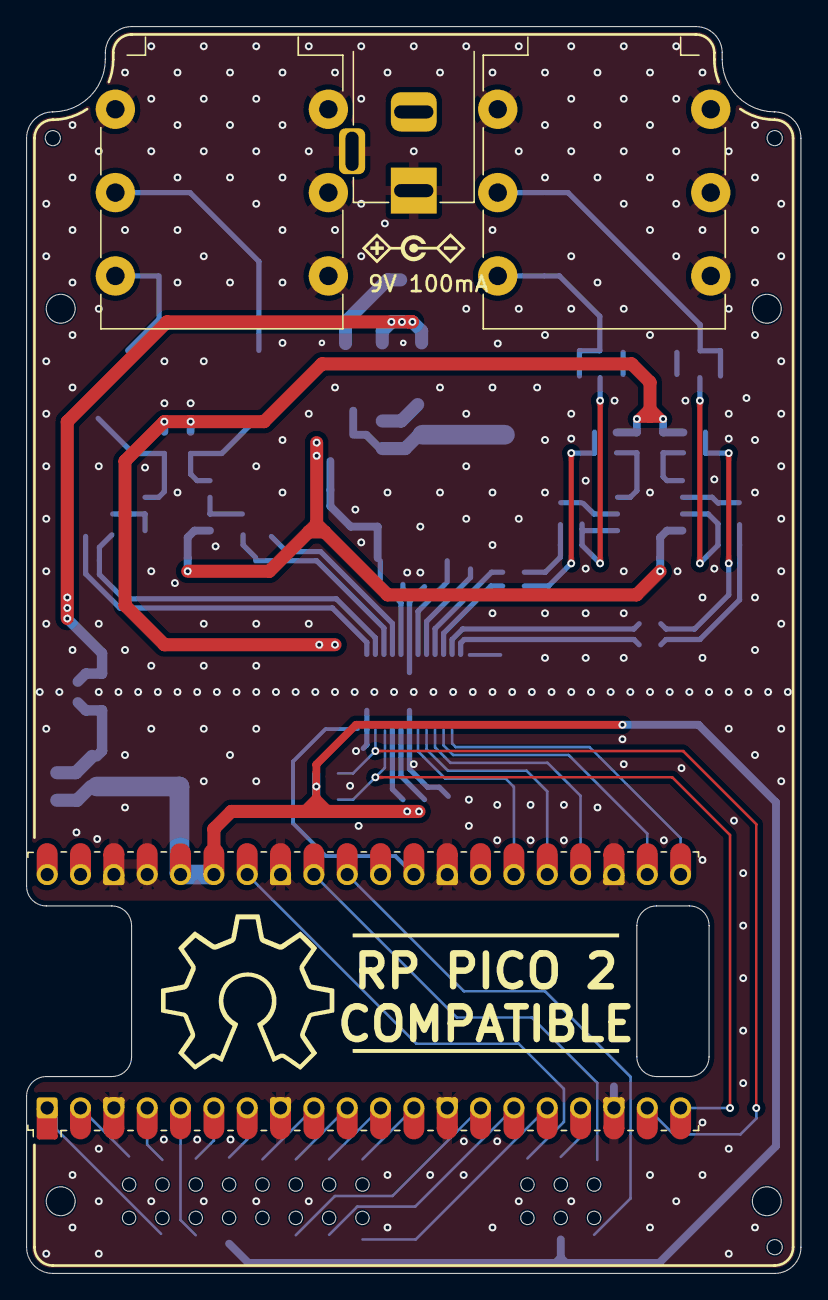
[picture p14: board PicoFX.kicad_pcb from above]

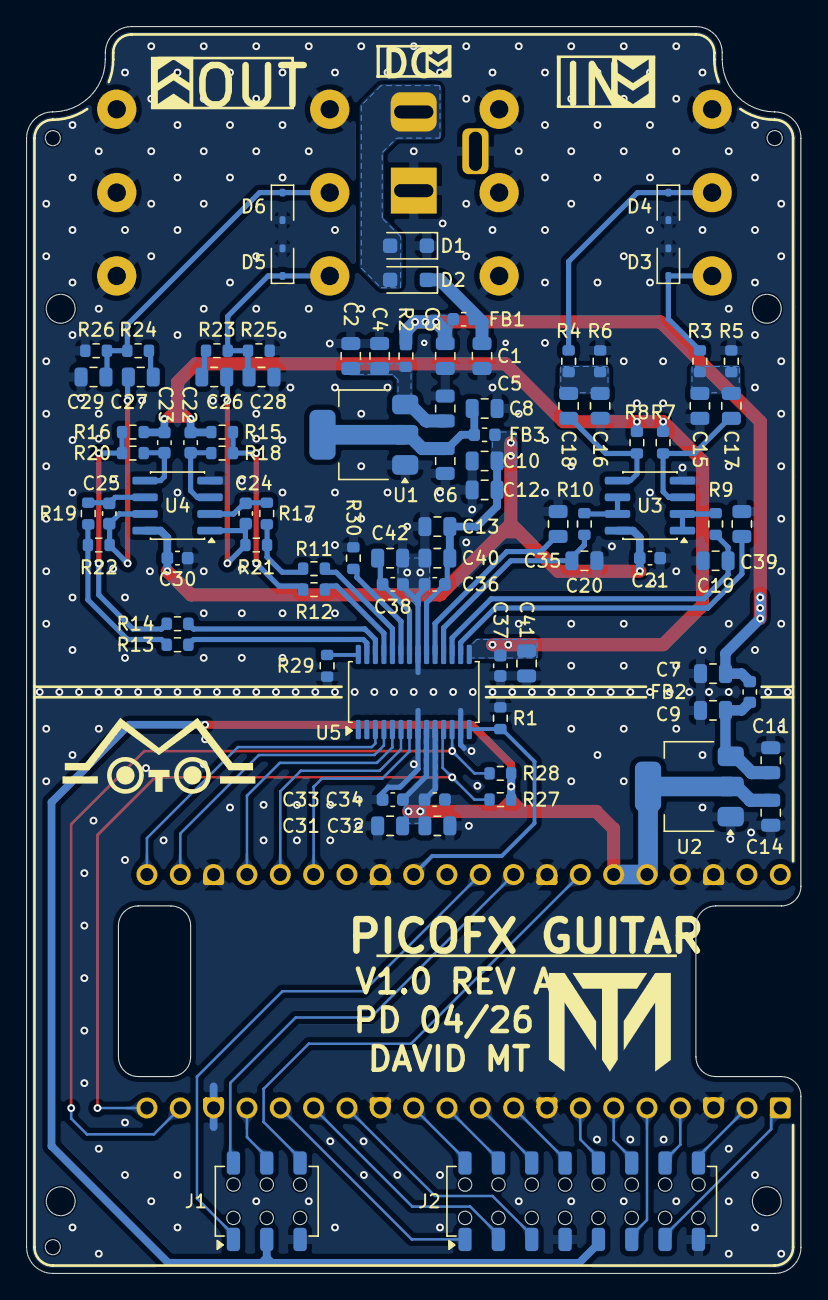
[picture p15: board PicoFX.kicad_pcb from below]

Board: 4 copper layers, 59.0 x 95.0 mm, 97 parts (92 on the bottom side), 68 nets.

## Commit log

2026-04-09 Schematic
    Updated the schematic.
    Added the codec schematic module.
    Added the buffer schematic module.
    Added the RP2350 schematic module.
    [Buffers_In.kicad_sch, Buffers_Out.kicad_sch, Codec.kicad_sch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]
2026-04-10 Schematic
    Updated the power delivery module.
    Other minor changes.
    [Buffers_In.kicad_sch, Buffers_Out.kicad_sch, Codec.kicad_sch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]
2026-04-12 Moved to a CS4272 codec as a cheaper alternative with similar performance.
    [Buffers_In.kicad_sch, Buffers_Out.kicad_sch, Codec.kicad_sch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]
2026-04-12 Initial layout
    Initial layout inside a 1590N1/125B pedal enclosure.
    [Buffers_In.kicad_sch, Buffers_Out.kicad_sch, Codec.kicad_sch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]
2026-04-13 RP2350 layout
    Updated the layout for the RP2350.
    Added board headers.
    [Buffers_In.kicad_sch, Buffers_Out.kicad_sch, Codec.kicad_sch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]
2026-04-15 Input buffer and power
    Updated the input buffer layout.
    Updated the power supply layout.
    [Buffers_In.kicad_sch, Buffers_Out.kicad_sch, Codec.kicad_sch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]
2026-04-15 Codec layout
    Updated the codec layout.
    [Buffers_In.kicad_sch, SimpleCodec.kicad_pcb]
2026-04-15 Missing connections
    Updated the board layout.
    Added al missing connections.
    [Buffers_In.kicad_sch, SimpleCodec.kicad_pcb, SimpleCodec.kicad_sch]
2026-04-16 Initial mounting holes
    Added some minimal mounting holes.
    Need to review the positioning.
    [SimpleCodec.kicad_pcb, SimpleCodec.kicad_sch]
2026-04-16 Silkscreen design
    Updated the silkscreen for the PCB.
    [SimpleCodec.kicad_pcb, SimpleCodec.kicad_sch]
2026-04-18 Build materials
    Uploaded all files required for assembly.
    [BOM.xlsx, Buffers_In.kicad_sch, Buffers_Out.kicad_sch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]
2026-04-19 Silkscreen and notes
    Updated the board silkscreen.
    Updated VCOM capacitance value.
    [Codec.kicad_sch, SimpleCodec.kicad_pcb]
2026-04-19 Silkscreen and build
    Updated the silkscreen of the PCB.
    Updated all build files.
    [BOM.xlsx, SimpleCodec.kicad_pcb]
2026-04-21 Silkscreen logos
    Addedd some logos to the silkscreen layer.
    [SimpleCodec.kicad_pcb]
2026-04-25 Layout revision
    Minor updated to references.
    Minor updated to the PCB layout.
    [Buffers_In.kicad_sch, Buffers_Out.kicad_sch, Codec.kicad_sch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]
2026-04-25 Layout optimization
    Optimized the PCB layout.
    [PicoFX.kicad_pcb]
2026-04-25 Output files
    Updated the build files.
    [PicoFX.kicad_pcb]
